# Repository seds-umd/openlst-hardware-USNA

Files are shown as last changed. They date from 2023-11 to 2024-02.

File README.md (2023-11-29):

# OpenLST Development/BPP Board

OpenLST board for SEDS@UMD modified by Nathan Kerns. The latest version of Kicad 6 Nightlies is required to view or modify the design. Recent pdf exports of the PCB and schematic are available in the pdf folder, but may not be completely up to date.

[Interactive BOM](https://harmalkar.github.io/satellite-prototype/ibom.html)

## BOM

BOM is automatically generated in KiCAD using "bom_csv_grouped_by_value" script, and manually separated into formats seen in bom folder. `openlst-bom.csv` contains entire BOM, `openlst-bom-digikey.csv` contains Digikey components, and `openlst-bom-mouser.csv` contains Mouser components.

## Power Budgets

3.3 V - 85 mA

* CC1110 - 50 mA max
* ASFL1-27MHz - 15 mA max
* TLV803S - 15 mA max
* PE4259 - <1 mA
* RFFM6404 - <1 mA

4.2 V - 600 mA

* RFFM6404 - 600 mA max

## Frequency Range

430-445 MHz

* CC1110 - 391-464 MHz
* SF2446E - 425-445 MHz
* RFFM6404 - 430-450 MHz

## Temperature Range

Constraining component is ASFL1-27MHz at -20 to 70 C

## PCB

Layers
* F.Cu - GND plane + signals
* In1.Cu - GND plane
* In2.Cu - Power planes
* B.Cu - GND plane + signals

50 ohm traces
* 6 mil (0.15 mm) clearance
* 13.4 mil (0.34 mm) width
* Via fence on 50x50 mil (1.27x1.27 mm) grid

Other traces
* 0.2 mm (8 mil) signal traces
* 0.3 mm (12 mil) power traces
* Power planes for high current paths

## Dimensions

* Board size: 50x43mm (not including SMA connector)
* Hole pattern: 43x36mm, M3 clearance hole (3.2mm diameter), screw head up to 6.5mm diameter

# Original readme

OpenLST Reference Hardware
==========================

This repository contains a KiCad project with a hardware reference
implementation for the OpenLST.  This design is a simplified version
of the Texas Instruments CC1110 432 MHz reference design.  A 1 watt
power amplifier module has been added to increase operating range.
The design is intended for use at 437 MHz, however, it may be modified
for use at other frequencies.

The user is responsible for obtaining and maintaining the necessary
license to operate this radio.  The example project uses frequencies
in the US Amateur Radio UHF band. Transmissions in this band require a
valid FCC license and compliance with CFR Part 97.

board rendering

Contents
--------

This repository contains the following items:

  * [KiCAD 4.0](http://kicad-pcb.org/) project with self-contained part library
  * [Schematic](pdf/openlst-hw.pdf) in PDF form
  * [Bill of materials](bom/) with ordering information for components
  * [Gerber files](gerber/) for PCB fabrication

License & Legal Information
---------------------------

Copyright 2018 Planet Labs Inc. This work is licensed under a
Creative Commons Attribution-ShareAlike 4.0 International License.

This document may contain technology or software the export of which
is or may be restricted by the Export Administration Act and the
Export Administration Regulations (EAR), 15 C.F.R. parts
730-774. Diversion contrary to U.S. law is prohibited.

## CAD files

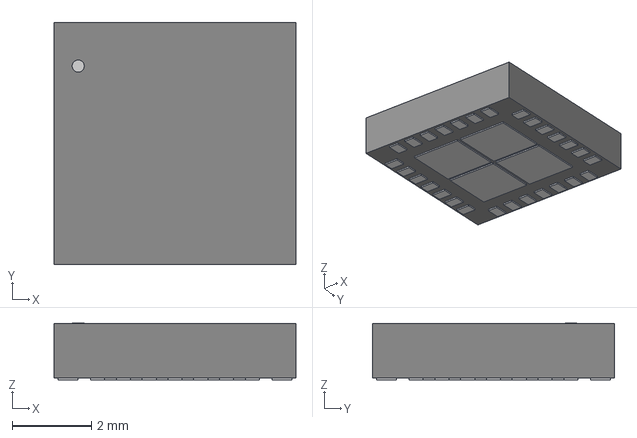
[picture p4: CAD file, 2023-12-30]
footprints/3D Models/IC28_ADL8111ACCZN_ADI.step
6.10 x 6.10 x 1.43 mm

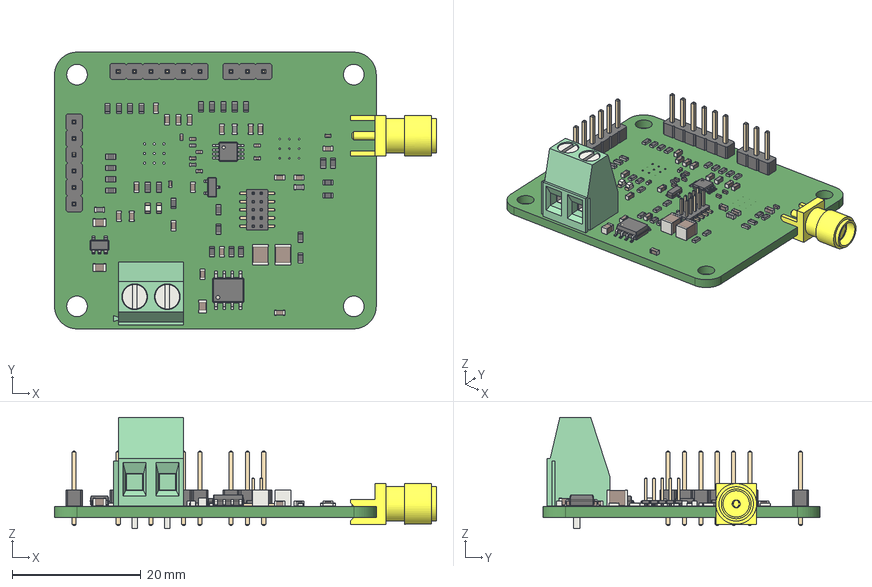
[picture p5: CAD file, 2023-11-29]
openlst-hw.step
59.4 x 43.0 x 17.3 mm

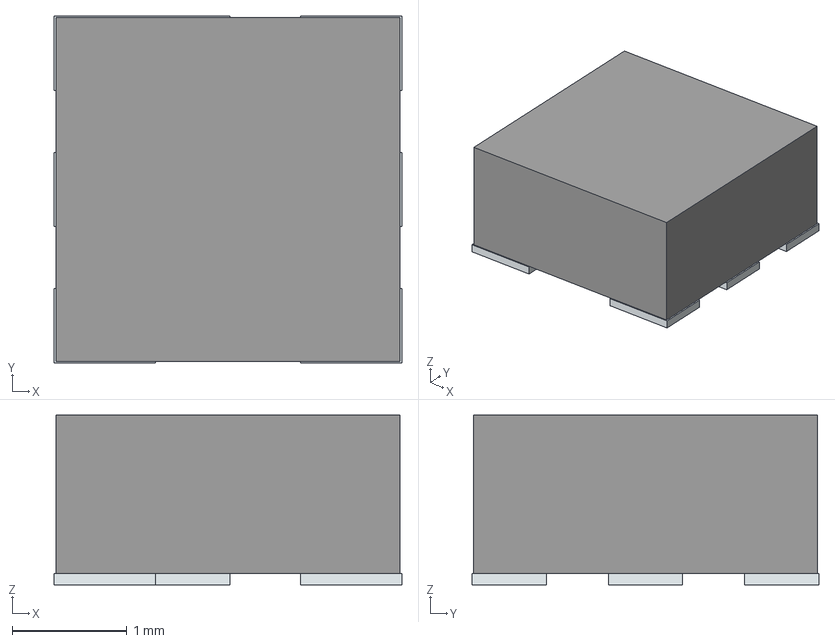
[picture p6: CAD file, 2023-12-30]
footprints/3D Models/SF2446E.stp
3.04 x 3.03 x 1.48 mm
Pins

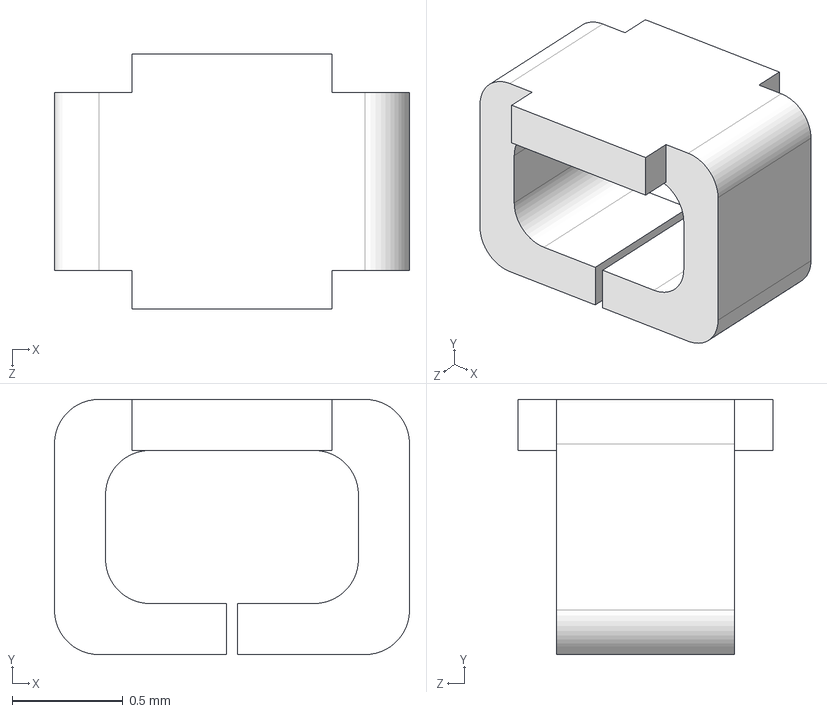
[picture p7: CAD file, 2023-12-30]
footprints/3D Models/RCUCTE.stp
1.60 x 1.15 x 1.15 mm

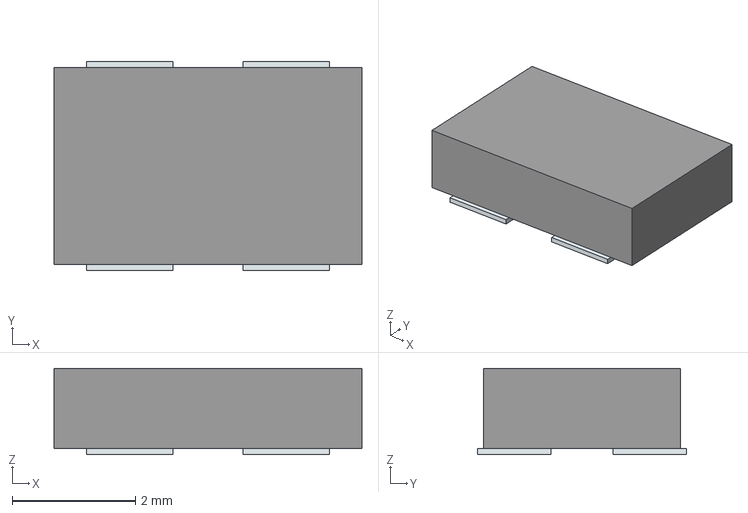
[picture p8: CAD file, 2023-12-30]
footprints/3D Models/ASFL1-27.000MHZ-LK-T.stp
5.00 x 3.40 x 1.40 mm
Pins

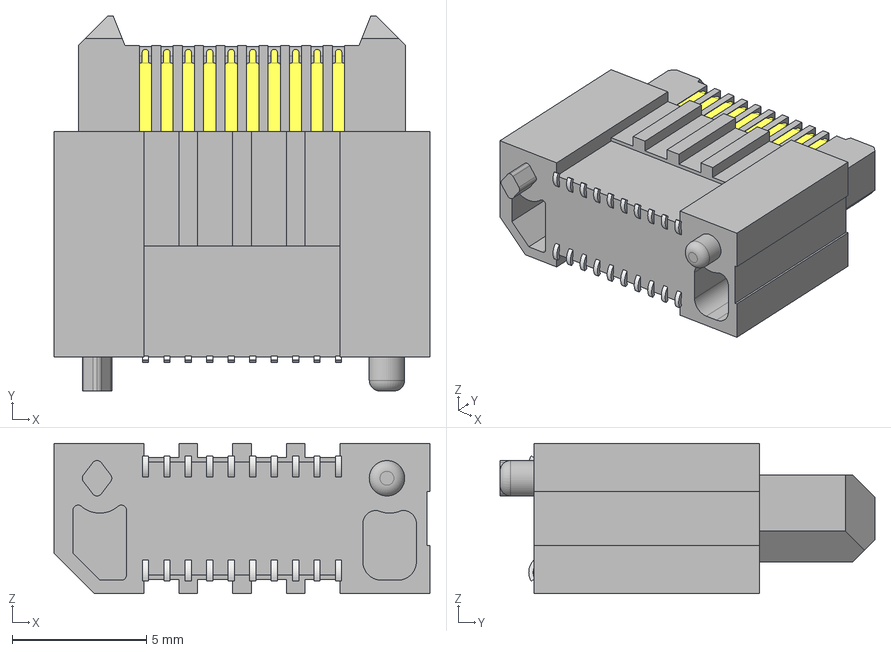
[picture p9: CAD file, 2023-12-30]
footprints/3D Models/ERM8-010-02.0-L-DV-TR.stp
14.0 x 14.0 x 5.60 mm
ERM8-010-09.0-DV3_pin
ERM8-010-09.0-DV_pin
ERM8-010-09.0-DVT

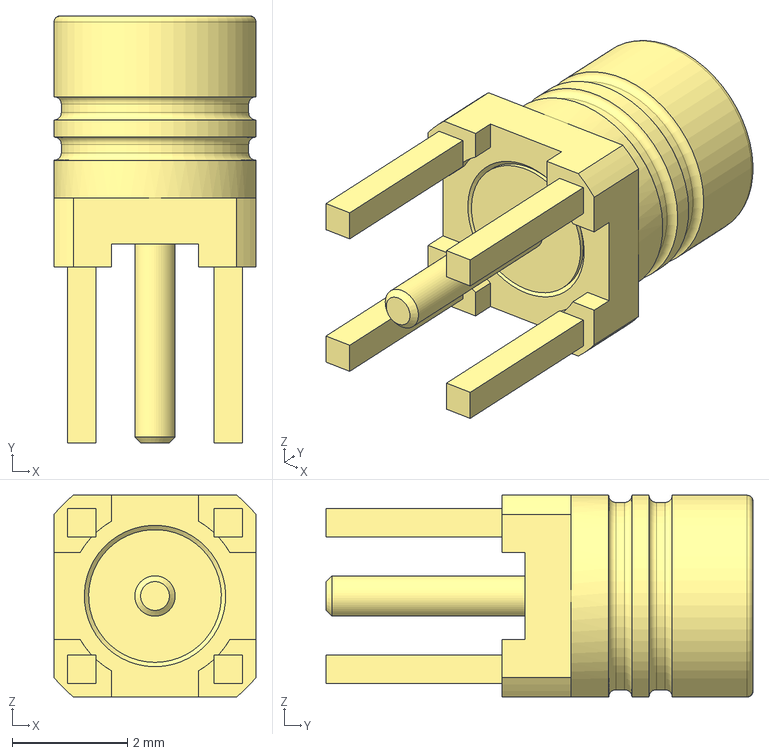
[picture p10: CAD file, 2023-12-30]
footprints/3D Models/MMCXV-J-P-HF-ST-TH1.step
3.50 x 7.40 x 3.50 mm

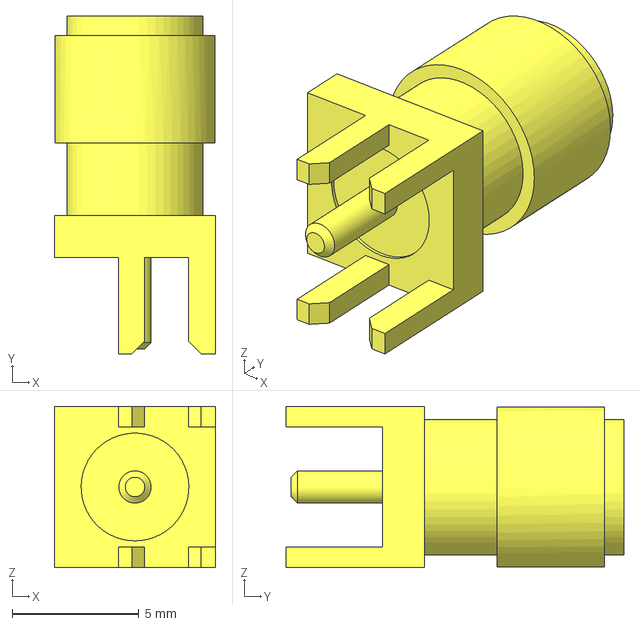
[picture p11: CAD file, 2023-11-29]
footprints/3D Models/SMA-J-P-H-ST-EM1.stp
6.35 x 13.3 x 6.35 mm

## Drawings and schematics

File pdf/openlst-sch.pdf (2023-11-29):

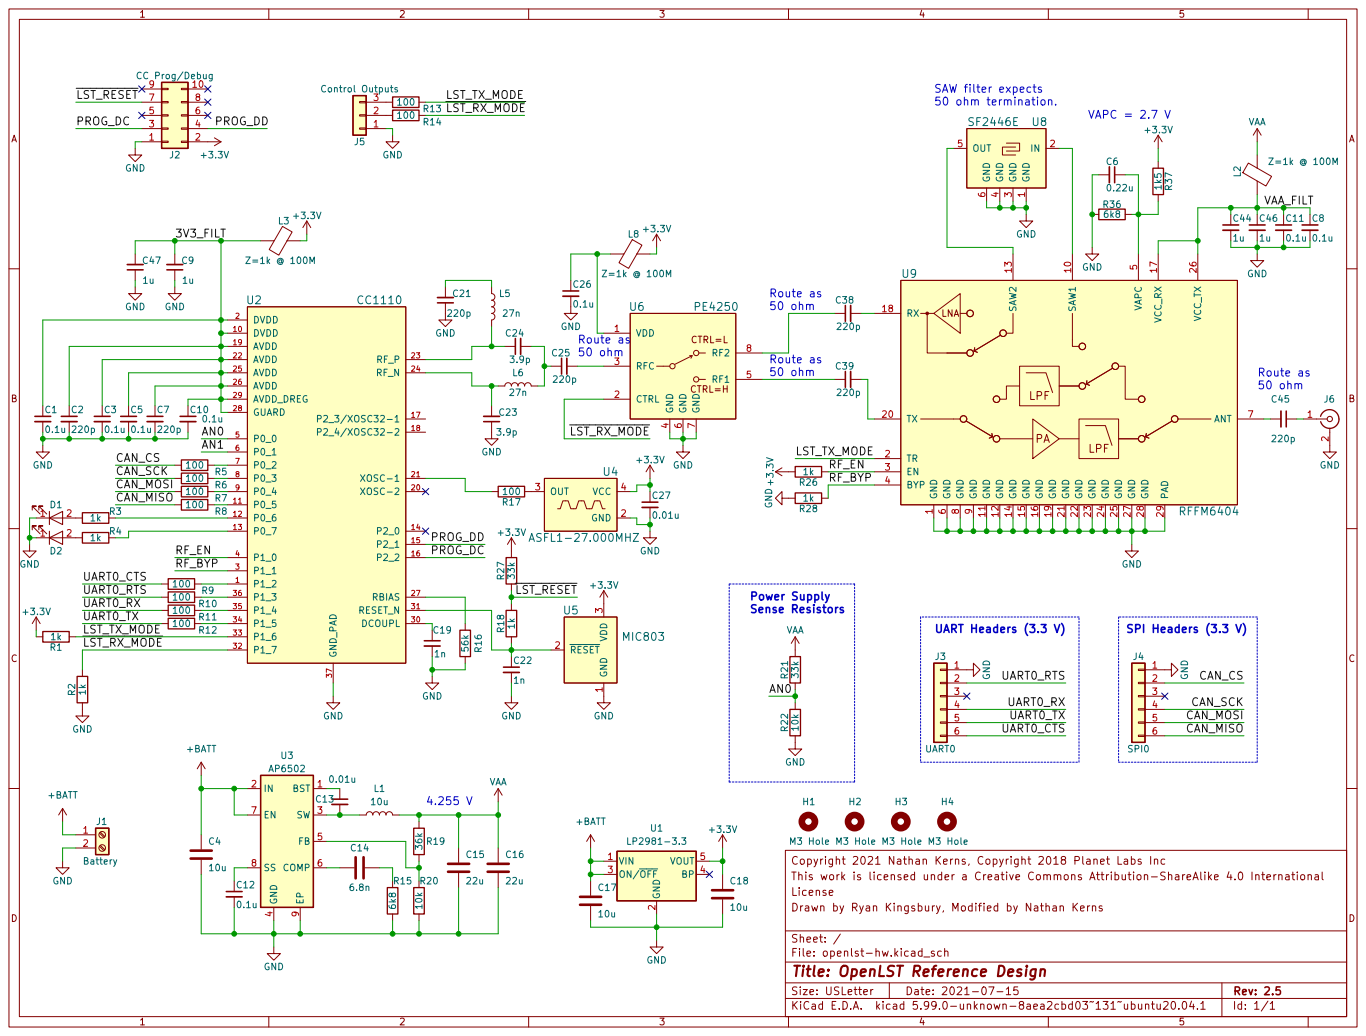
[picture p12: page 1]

SAW filter expects 50 ohm termination. Route as 50 ohm

1 SAW1 10 GND 11 GND 12 SAW2 13 GND 14 GND 15 GND 16 VCC_RX 17 RX 18 GND 19 TR 2 TX 20 GND 21 GND 22 GND 23 GND 24 GND 25 VCC_TX 26 GND 27 GND 28 PAD 29 EN 3 BYP 4 VAPC

7 VDD 1 CTRL 2 RFC 3 GND

UART0_CTS
UART0_RTS
UART0_RX
UART0_TX
File: openlst-hw.kicad_sch Sheet: / Drawn by Ryan Kingsbury, Modified by Nathan Kerns License This work is licensed under a Creative Commons Attribution-ShareAlike 4.0 International Copyright 2021 Nathan Kerns, Copyright 2018 Planet Labs Inc R1

9 U3 AP6502 R10 100 H2 M3 Hole H1 M3 Hole GND R22 10k R21 33k VAA GND

LST_TX_MODE
~{LST_RX_MODE}

4 FB 5 COMP 6 EN 7 SS 8 EP

2 ON/~{OFF} 3 BP 4 VOUT 5 U1

Id: 1/1 Title: OpenLST Reference Design

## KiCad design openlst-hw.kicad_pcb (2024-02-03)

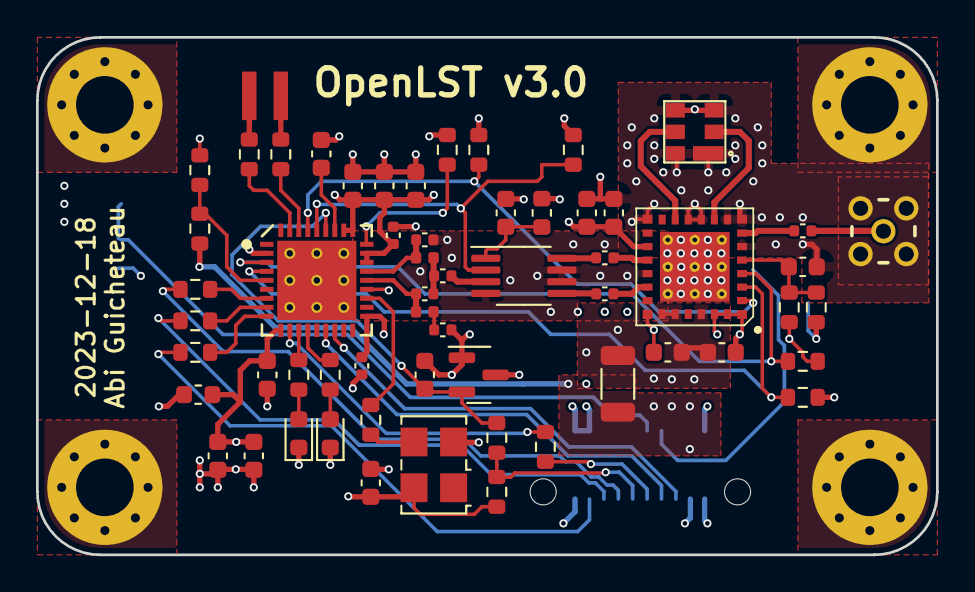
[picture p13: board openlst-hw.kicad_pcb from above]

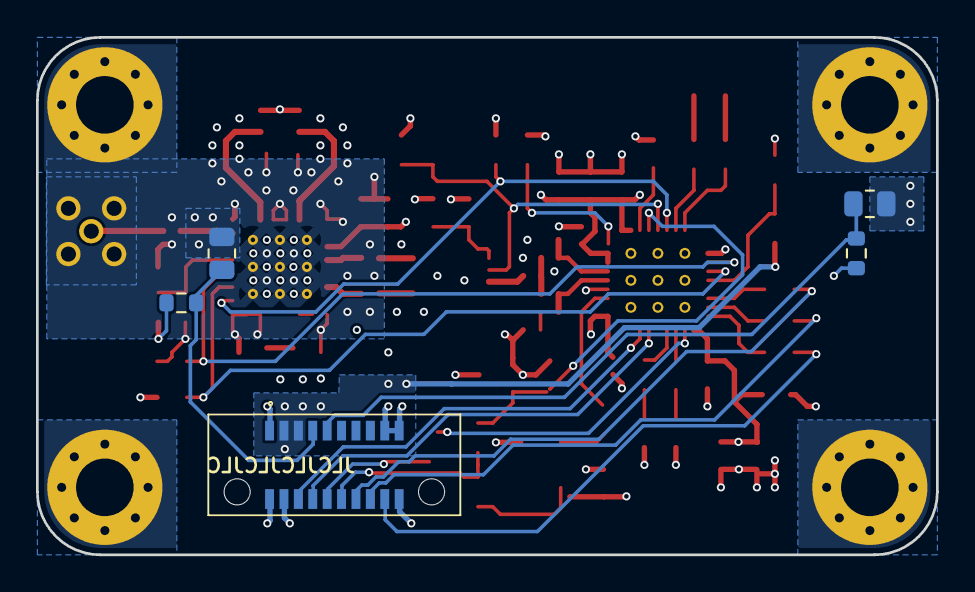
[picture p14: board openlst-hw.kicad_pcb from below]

Board: 4 copper layers, 50.0 x 28.8 mm, 69 parts (5 on the bottom side), 51 nets.

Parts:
C1, C3, C5, C8, C10, C11, C26: 0.1u; C_0603_1608Metric
C2, C7, C21, C25, C38, C39, C45: 220p; C_0402_1005Metric
C6: 0.22u; C_0603_1608Metric
C9, C44, C46, C47: 1u; C_0603_1608Metric
C19, C22: 1n; C_0603_1608Metric
C23, C24: 3.9p; C_0402_1005Metric
C27: 0.01u; C_0603_1608Metric
D1, D2: LED; LED_0603_1608Metric
H1, H2, H3, H4: M3 Hole; MountingHole_3.2mm_M3_Pad_Via
J3: Conn_02x10_Odd_Even; ERM8-010-YY.Y-XXX-DV-TR
J6: ANT; SAMTEC_MMCXV-J-P-HF-ST-TH1
L2: Z=1k @ 100M; L_1206_3216Metric
L3, L8: Z=1k @ 100M; L_0603_1608Metric
L5, L6: 27n; L_0402_1005Metric
R1, R2, R3, R4, R18, R26, R28: 1k; R_0603_1608Metric
R5, R6, R7, R8, R11, R12, R17: 100; R_0603_1608Metric
R9, R10, R22: 10k; R_0603_1608Metric
R16: 56k; R_0603_1608Metric
R21, R27: 33k; R_0603_1608Metric
R36: 6k8; R_0603_1608Metric
R37: 1k5; R_0603_1608Metric
TH1, TH2: Thermistor_NTC; R_0805_2012Metric
TP1, TP2: TestPoint; RCUCTE_0603_Test_Point
U2: CC1110; TI_CC_QFN36
U4: ASFL1-27.000MHZ; Oscillator_SMD_SeikoEpson_SG8002LB-4Pin_5.0x3.2mm
U5: MIC803; SOT-23
U6: PE4250; MSOP-8_3x3mm_P0.65mm
U7: RFFM6406; Qorvo_LGA_28_ThermalVias
U8: SF2446E; SAW-6_3.0mm

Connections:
+3V3: C27.1, J3.4, L3.1, L8.1, R1.2, R9.1, R10.1, R26.2, R27.2, R37.1, U4.4 (VCC), U5.3 (VDD)
/3V3_FILT: C1.1, C2.1, C3.1, C5.1, C7.1, C9.2, C10.1, C47.2, L3.2, U2.2 (DVDD), U2.10 (DVDD), U2.19 (AVDD), U2.22 (AVDD), U2.25 (AVDD), U2.26 (AVDD), U2.28 (GUARD), U2.29 (AVDD_DREG)
/AN0: R21.1, R22.2, U2.5 (P0_0)
/LST_TX_MODE: R1.1, U2.33 (P1_6), U7.2 (TR)
/PROG_DC: J3.6, U2.16 (P2_2)
/PROG_DD: J3.8, U2.15 (P2_1)
/RF_BYP: R28.1, U2.3 (P1_1), U7.4 (BYP)
/RF_EN: R26.1, U2.4 (P1_0), U7.3 (EN)
/UART0_RX: R11.2, TP1.1
/UART0_TX: R12.2, TP2.1
/UART_CTS_1: J3.14, R5.2
/UART_RTS_1: J3.16, R6.2
/UART_RX_1: J3.10, R8.2
/UART_TX_1: J3.18, R7.2
/VAA_FILT: C8.1, C11.1, C44.1, C46.1, L2.2, U7.17 (VCC_RX), U7.23 (VDD), U7.24 (VCC_TX1), U7.26 (VCC_TX2)
/~LST_RESET: J3.12, R18.2, R27.1
/~LST_RX_MODE: R2.1, U2.32 (P1_7), U6.2 (CTRL)
GND: C1.2, C2.2, C3.2, C5.2, C6.2, C7.2, C8.2, C9.1, C10.2, C11.2, C19.2, C21.1, C22.2, C23.1, C26.2, C27.2, C44.2, C46.2, C47.1, D1.1 (K), D2.1 (K), H1.1, H2.1, H3.1, H4.1, J3.1, J3.2, J3.17, J3.19, J3.20, J6.2 (Ext), R2.2, R16.1, R22.1, R28.2, R36.2, TH1.2, TH2.2, U2.37 (GND_PAD), U4.2 (GND), U5.1 (GND), U6.4 (GND), U6.6 (GND), U6.7 (GND), U7.1 (GND), U7.6 (GND), U7.8 (GND), U7.9 (GND), U7.11 (GND), U7.12 (GND), U7.15 (GND), U7.19 (GND), U7.21 (GND), U7.22 (GND), U7.27 (GND), U7.28 (GND), U7.29 (PAD), U8.1 (GND), U8.3 (GND), U8.4 (GND), U8.6 (GND)
unnamed: C21.2, L5.1
unnamed: C24.2, C25.1, L6.2
unnamed: D1.2 (A), R3.1
unnamed: D2.2 (A), R4.1
unnamed: C45.1, J6.1 (In)
unnamed: C19.1, U2.30 (DCOUPL)
unnamed: R5.1, U2.7 (P0_2)
unnamed: R6.1, U2.8 (P0_3)
unnamed: R7.1, U2.9 (P0_4)
unnamed: R8.1, U2.11 (P0_5)
unnamed: R3.2, U2.12 (P0_6)
unnamed: R4.2, U2.13 (P0_7)
unnamed: R11.1, U2.35 (P1_4)
unnamed: R12.1, U2.34 (P1_5)
unnamed: R16.2, U2.27 (RBIAS)
unnamed: C22.1, R18.1, U2.31 (RESET_N), U5.2 (~RESET)
unnamed: C23.2, L6.1, U2.24 (RF_N)
unnamed: C24.1, L5.2, U2.23 (RF_P)
unnamed: R17.2, U2.21 (XOSC-1)
unnamed: R17.1, U4.3 (OUT)
unnamed: C39.1, U6.5 (RF1)
unnamed: C38.1, U6.8 (RF2)
unnamed: C25.2, U6.3 (RFC)
unnamed: C26.1, L8.2, U6.1 (VDD)
unnamed: C45.2, U7.7 (ANT)
unnamed: C38.2, U7.18 (RX)
unnamed: U7.10 (SAW1), U8.2 (IN)
unnamed: U7.13 (SAW2), U8.5 (OUT)
unnamed: C39.2, U7.20 (TX)
unnamed: C6.1, R36.1, R37.2, U7.5 (VAPC)
TEMP_OUT_0: J3.7, R9.2, TH1.1
TEMP_OUT_1: J3.9, R10.2, TH2.1
VAA: J3.3, J3.5, L2.1, R21.2

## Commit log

2023-11-29 initial file transfer from openlst-hardware
    [CAN_sheet.kicad_sch, SMA-J-P-H-ST-EM1.stp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]
2023-12-11 changed connectors, halfway through pcb
    [openlst-hw.kicad_pcb, openlst-hw.kicad_sch]
2023-12-18 finished edits v1
    [openlst-hw.kicad_pcb, openlst-hw.kicad_sch]
2023-12-19 finished edits v2
    [openlst-hw.kicad_pcb, openlst-hw.kicad_sch]
2023-12-30 fixed rf connection and power lines
    [openlst-hw.kicad_pcb]
2023-12-30 rotated ferrite bead and added 3d models
    [ASFL1-27.000MHZ-LK-T.stp, ERM8-010-02.0-L-DV-TR.stp, IC28_ADL8111ACCZN_ADI.step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]
2023-12-30 changed 3d library
    [openlst-hw.kicad_pcb]
2024-01-05 added thermal reliefs and thermistors
    [openlst-hw.kicad_pcb, openlst-hw.kicad_sch]
2024-01-09 adjusted border and mounting holes
    [openlst-hw.kicad_pcb]
2024-01-27 changed thermistor part numbers
    [openlst-hw.kicad_sch]
2024-01-27 changed bom to reflect obc
    [openlst-hw.kicad_sch]
2024-01-30 adjusted BOM headers
    [openlst-hw.kicad_sch]
2024-01-30 fixed typo in bom
    [openlst-hw.kicad_sch]
2024-01-30 fixed TR components
    [openlst-hw.kicad_sch]
2024-01-31 changed MMCXV-J-P-HF-ST-TH1 to a digikey part
    [openlst-hw.kicad_sch]
2024-02-01 changed solder mask values in board setup
    [openlst-hw.kicad_pcb]
2024-02-03 added jlc order num
    [openlst-hw-B_Cu.gbl, openlst-hw-B_Mask.gbs, openlst-hw-B_Paste.gbp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]
2024-02-13 Add interactive BOM

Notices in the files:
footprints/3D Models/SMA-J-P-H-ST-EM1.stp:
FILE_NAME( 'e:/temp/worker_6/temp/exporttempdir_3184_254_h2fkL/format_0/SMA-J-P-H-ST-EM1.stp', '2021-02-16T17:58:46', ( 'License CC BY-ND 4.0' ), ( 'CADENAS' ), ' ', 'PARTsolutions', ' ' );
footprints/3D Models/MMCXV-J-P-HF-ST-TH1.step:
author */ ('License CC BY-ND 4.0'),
